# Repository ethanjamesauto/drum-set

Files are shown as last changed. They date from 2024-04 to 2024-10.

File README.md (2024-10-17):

## Project Overview
This project aims to produce an electronic drum set that is silent yet feels nearly identical to a real acoustic drum set. I've split the project into two phases:
* Phase 1 - creating a basic kit with a kick drum trigger and 2 drum pads as a proof-of-concept **(completed)**
* Phase 2 - creating a full drum kit with kick trigger, 4 drum pads, and 4 electronic cymbals **(in progress)**

## Full Outline

### Drum Module
* I'm currently using an ESP32 with [edrumulus](https://github.com/corrados/edrumulus/tree/main) and a custom-built analog frontend
  * The ESP32 has a drawback of not being a native MIDI device - it requires a script to appear as a virtual MIDI device
  * I'll be replacing it with a teensy 4.2, which solves this issue. Additionally, it has an SD card slot and plenty of processing power, so hopefully I'll be able to use it as a standalone synthesizer.
* I'm currently designing a PCB which includes the teensy, 8 input jacks, analog frontends for each channel, and display/keypad for controlling settings

Materials:
* Teensy 4.2
* 8x 1/4 inch PCB mount TRS audio jacks
* 16x2 character LCD
* Arduino numeric keypad
* 8x TRS audio cable

Features:
* Teensy 4.2 based - with headers for all GPIOs
* headers for piezo inputs (test points)
* i2c headers for display (VCC, GND, SDA, SCL)
* 8 gpios for numeric keypad

### Drum Pads
Materials:
  * Drum Shells
  * Drum top/bottom
  * M6x50mm bolts / M6 wing nuts (2x8 + 2x10 = 36 total)
  * Regular M6 nuts for attaching drum mount
  * M3x10mm bolts/nuts (already own)
  * 2x10in drum head, 2x12in drum head
  * piezos/trigger cones/audio jacks

Notes:
* All drum shells will be printed with [shell.scad](shell.scad) (my script for generating drum shells)
* Drum design is from [Open E-Drums](https://open-e-drums.com/hardware/download_pad_noshell.html)

### Hi-Hat
* Will likely use this [optical hi-hat controller](https://open-e-drums.com/hardware/download_hhc.html)

### Mounting Hardware
Rack will likely be a second-hand alesis e-drum rack

TODO:
* modify pcb to allow for optical hi hat sensor

Tom mounts:
*  [Alesis drum clamp mount](https://www.printables.com/model/244788-alesis-electronic-drum-clamp-mount) - these each require an Alesis L-rod
* Modify this [Roland mount](https://open-e-drums.com/hardware/download_mount.html) to change the hole from 11mm (Roland) to 9mm (Alesis)

Snare mount:
* ???

Cymbal Mounts:
* These could use the same alesis drum clamp mounts, but they require a cymbal mount instead of an L-rod (much more expensive)

Hi-Hat Mount:
* Real hi-hat stand. It's really not worth bothering with anything else.

## Members
Ethan James, Computer Engineering Student (2024) -
ethanjamesauto@vt.edu

## Images
Drum module PCB:
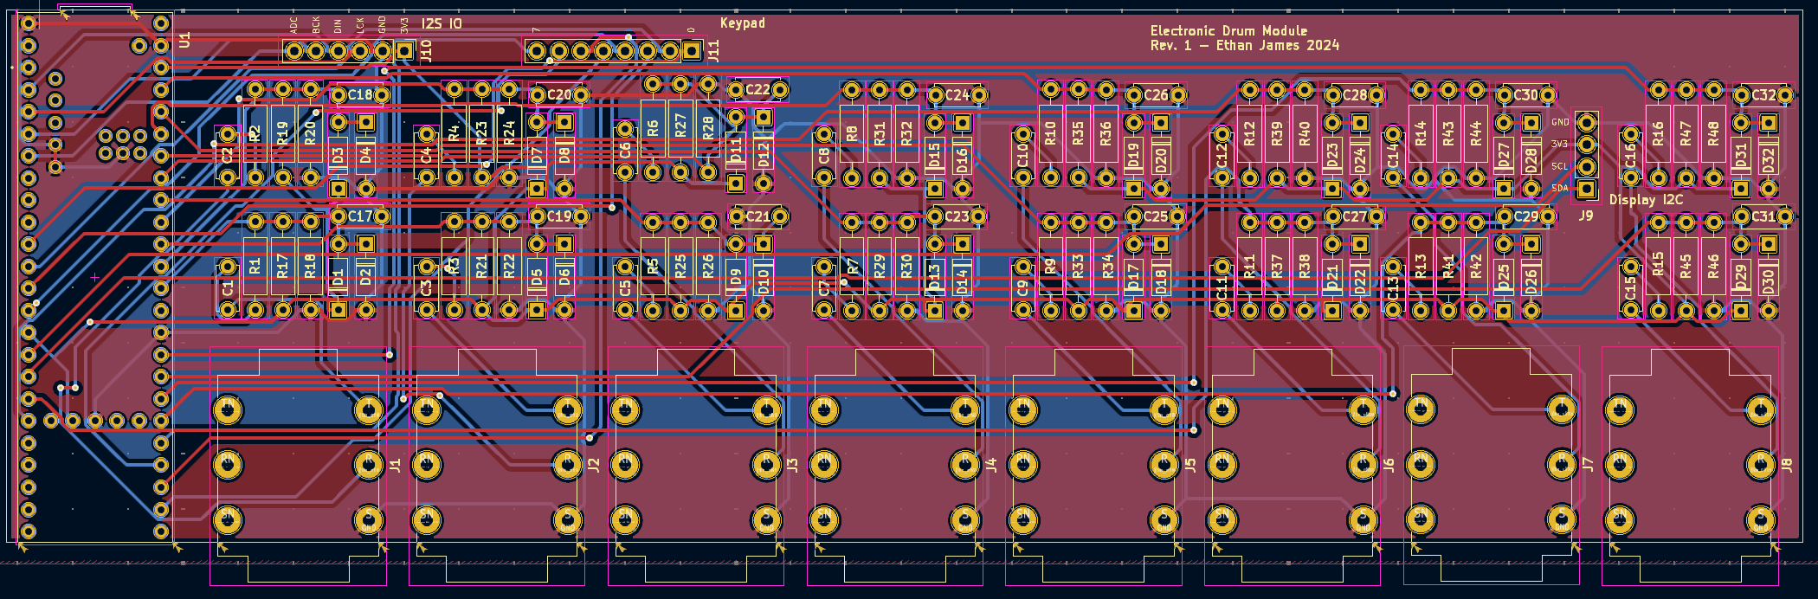
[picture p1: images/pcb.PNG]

This is the prototype (Phase 1):
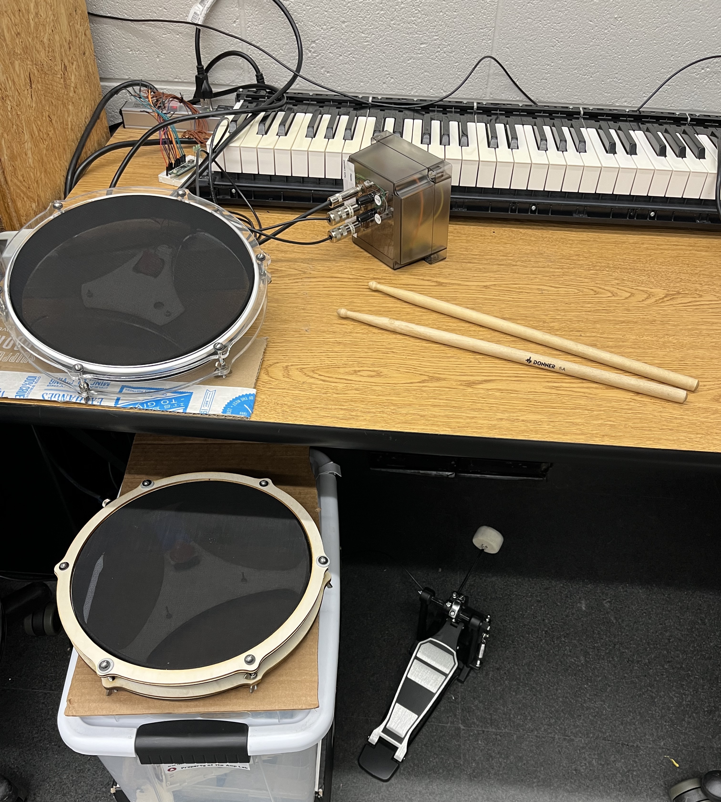
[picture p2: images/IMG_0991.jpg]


## Drum pad notes
* height from base plate is 47.5mm
* Trigger cones are 35mm tall
* Recommended height of trigger cone above shell is maybe 1.5mm or 1/16in
* definitely use spacers (3d printed or some other plastic) to adjust height of plate

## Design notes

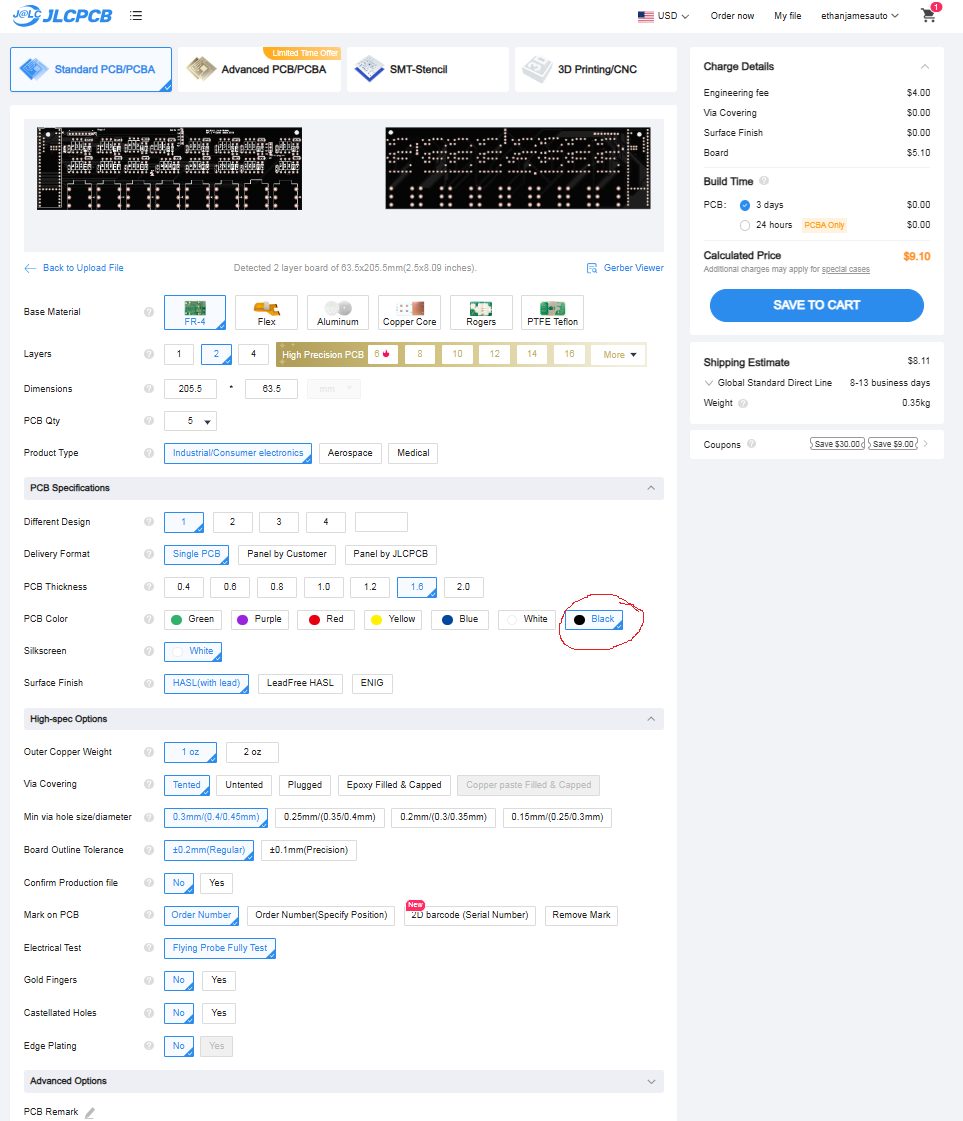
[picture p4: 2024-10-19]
drum_board/options.PNG

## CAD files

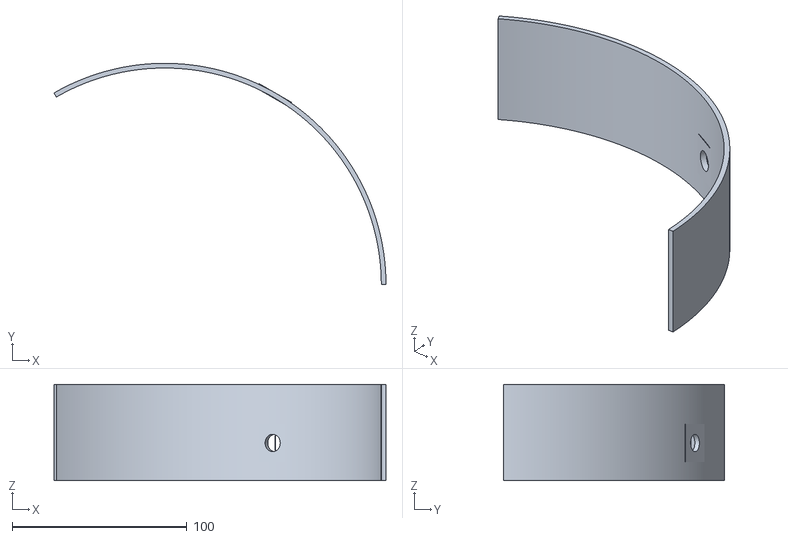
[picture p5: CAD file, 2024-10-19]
3d-print/shell_10in_jack.stl
190.2 x 126.8 x 55.0

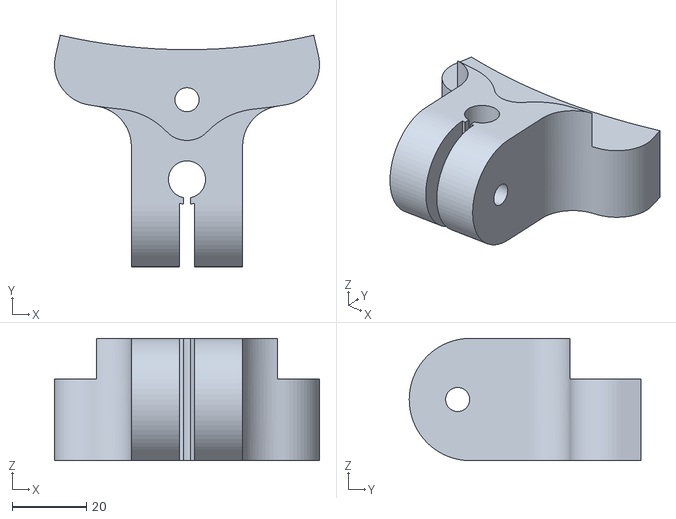
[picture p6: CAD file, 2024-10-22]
alesis-coupler/alesis.stl
71.5 x 62.5 x 33.0

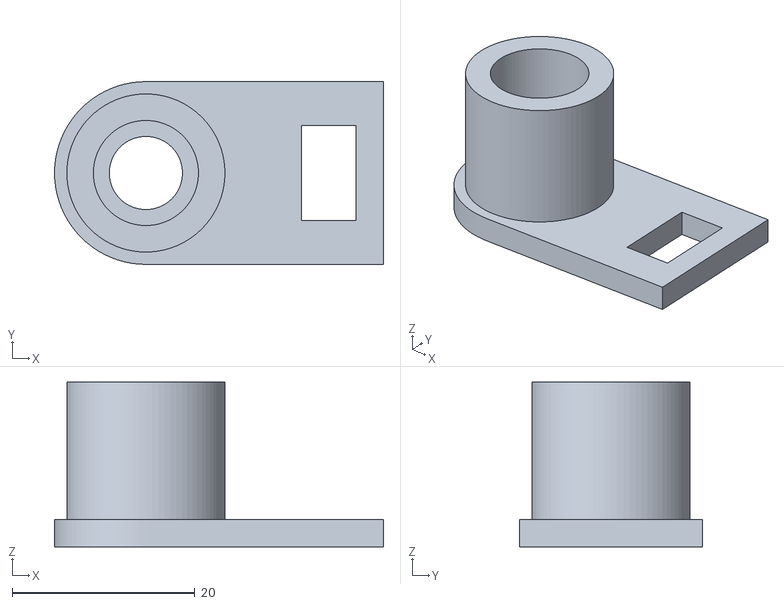
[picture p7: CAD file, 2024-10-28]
hi-hat-sensor/sensor.stl
36.0 x 20.0 x 18.0

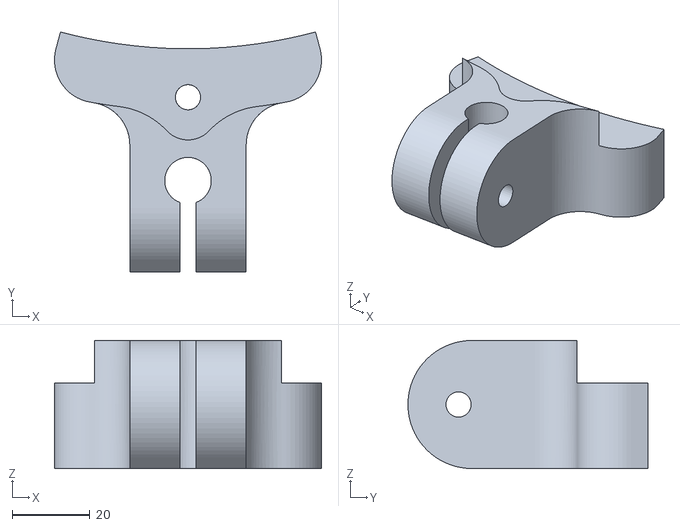
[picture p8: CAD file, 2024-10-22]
alesis-coupler/Mount_Roland_10_noshell.stl
68.8 x 61.9 x 33.0

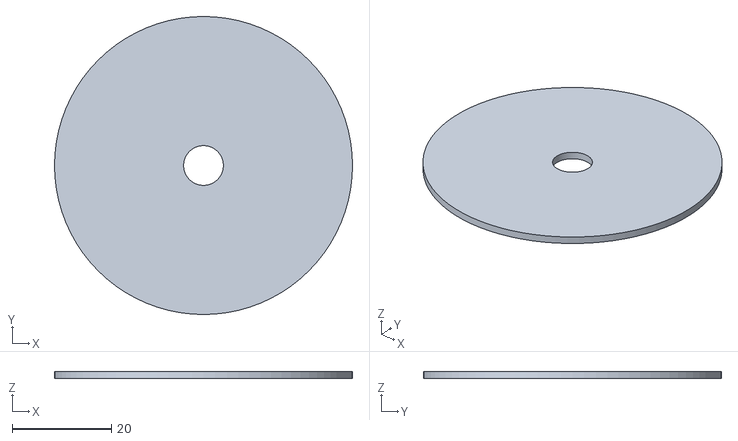
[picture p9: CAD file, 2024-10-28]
hi-hat-sensor/disc.stl
60.0 x 60.0 x 1.50

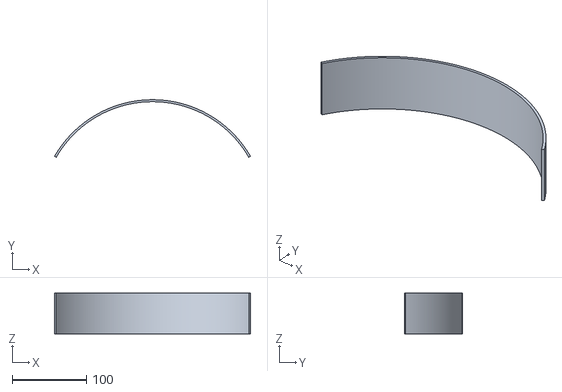
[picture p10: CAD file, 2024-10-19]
3d-print/shell_12in.stl
263.6 x 77.5 x 55.0

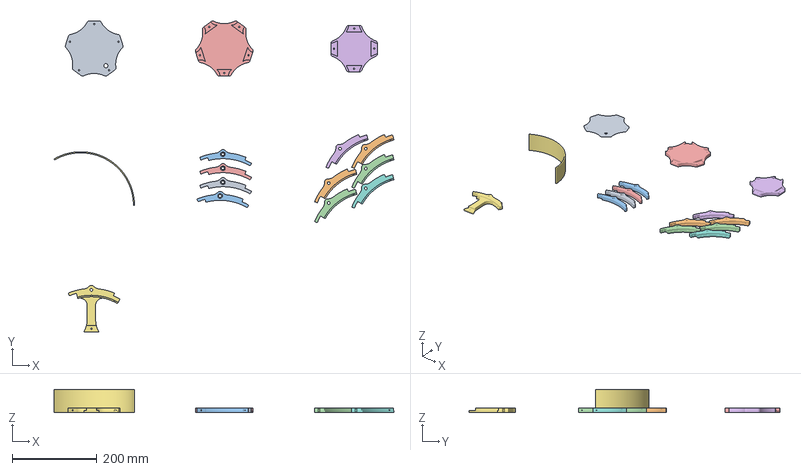
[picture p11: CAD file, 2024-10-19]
3d-print/drum_project.3mf
803.1 x 734.9 x 55.0 mm
sensorplate_12inch.stl
bottom2__noShell_10inch.stl x 6
rim_low_10inch.stl x 4
shell_10in.stl
bottom3_12inch.stl
bottom3_10inch.stl
bottom1_noShell_10inch.stl

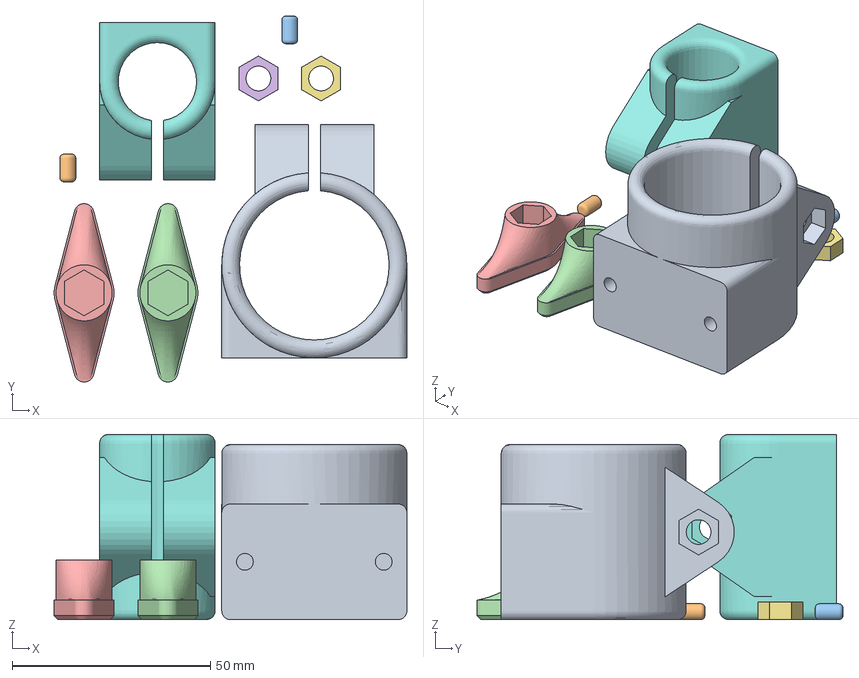
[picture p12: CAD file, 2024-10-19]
3d-print/Alesis Clamp II.3mf
89.0 x 92.3 x 46.7 mm
Alesis Clamp II-Big Clamp.stl
Alesis Clamp II-Dowel.stl
Alesis Clamp II-Knob.stl
Alesis Clamp II-Knob Insert.stl
Alesis Clamp II-Small Clamp.stl

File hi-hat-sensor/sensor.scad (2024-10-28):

// diameter of the hi-hat plastic thingy that the bottom hat rests on
stand_plastic_r = 11.3/2;

// radius of the hole the moving part fits through
hole_r = 8/2;

// outer diameter of this part
outer_r = 10;

// part thickness and height
thickness = 3;
height = 15;

tol_tight = 0.1;
tol_loose = 0.2;

platform_w = 26;
platform_h = outer_r*2;

tcrt_w = 10.2    + tol_tight*2;
tcrt_h = 5.8     + tol_tight*2;
tcrt_offset = 20 - tcrt_h/2;

disc_thick = 1.5;
disc_r = 30;

clutch_r = 9.3/2;

sensor_mount();
// disc();

module sensor_mount() {
	difference() {
		translate([0, 0, -thickness]) {
			cylinder(thickness, outer_r, outer_r, $fn=80);
			translate([0, -platform_h/2, 0]) cube([platform_w, platform_h, thickness]);
		}
		
		union() {
			translate([tcrt_offset, -tcrt_w/2, -thickness]) cube([tcrt_h, tcrt_w, thickness]);
			translate([0, 0, -thickness]) cylinder(thickness, hole_r, hole_r, $fn=80);
		}
	}

	difference() {
		cylinder(height, stand_plastic_r+thickness, stand_plastic_r+thickness, $fn=80);
		cylinder(height, stand_plastic_r+tol_tight, stand_plastic_r+tol_tight, $fn=80);
	}
}

module disc() {
	r = clutch_r + tol_loose;
	difference() {
		cylinder(disc_thick, disc_r, disc_r, $fn=80);
		cylinder(disc_thick, r, r, $fn=80);
	}
}

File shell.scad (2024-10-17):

module pieSlice(a, r, h){
  // a:angle, r:radius, h:height
  rotate_extrude(angle=a, $fn=500) square([r,h]);
}

// Note: no idea why there's a .008 here. It is equal to .2mm though - maybe it's a tolerance?
outer_rad = 10.008*25.4/2;	// 10 inch
// outer_rad = 12.008*25.4/2; 		// 12 inch

// thickness appears to be 3, so im doing 2.7
tol = 0.3;
tol_tight = 0.1;
tol_loose = 0.2;

// h = 32; // from the original drum prototype
h = 55;

rotate([0, 0, -30])
shell();

/*
rotate([0, 0, -30]) {
difference() {
	shell();
	jack(true, 1.8);
}
difference() {
	jack(true, 1.8);
	jack(false, 1.8);
}
}
//*/

module shell() {
	// from https://www.instructables.com/E-drum-With-Small-3D-Printer-and-Thick-Paper/
	rotate([0, 0, 30])
	difference() {
		pieSlice(120,outer_rad-tol,h);
		pieSlice(360, outer_rad-tol-2.7,h);
	}
}

module jack(cutout, offset) {
	// the top of the drum shell (that is not covered by the sides of the mesh head
	// is about 15mm from the top
	// the visible bottom is about 3mm from the bottom
	jack_height = ((h-15) + 3)/2;  // TODO: figure out
	jack_r = 9.6/2;
	hole_r = jack_r + tol_loose;
	cube_h = 3;
	cutout_h = jack_r*4.5;
	
	translate([0, outer_rad, jack_height])
	rotate([90, 0, 0]) {
		if (cutout)
			translate([0, 0, offset]) cube([cutout_h, cutout_h, cube_h], center=true);
		else
			cylinder(100, hole_r, hole_r, $fn=50);
	}
}

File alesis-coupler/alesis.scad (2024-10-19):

// The inner diameter of the 3d printed roland mount is 12mm
// the existing stl also uses an exactly 12mm hole
//*
translate([300, 0, 100]) 
import("Mount_Roland_12_noshell.stl");
//*/

inner = 9;
outer = 13.5;
h = 33;
fn = 50;
notch_w = 2;
notch_h = 20;

translate([-25, 11.5, 0])
translate([0, 0, -14.5])
difference () {
	cylinder(h, outer/2, outer/2, $fn=fn);
	union() {
		cylinder(h, inner/2, inner/2, $fn=fn);
		translate([-notch_w/2, -notch_h, 0])
			cube([notch_w, notch_h, h]);
	}

}

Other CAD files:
3d-print/shell_10in.stl
alesis-coupler/alesis_10.stl
alesis-coupler/Mount_Roland_12_noshell.stl
3d-print/shell_12in_jack.stl
alesis-coupler/alesis_10.scad

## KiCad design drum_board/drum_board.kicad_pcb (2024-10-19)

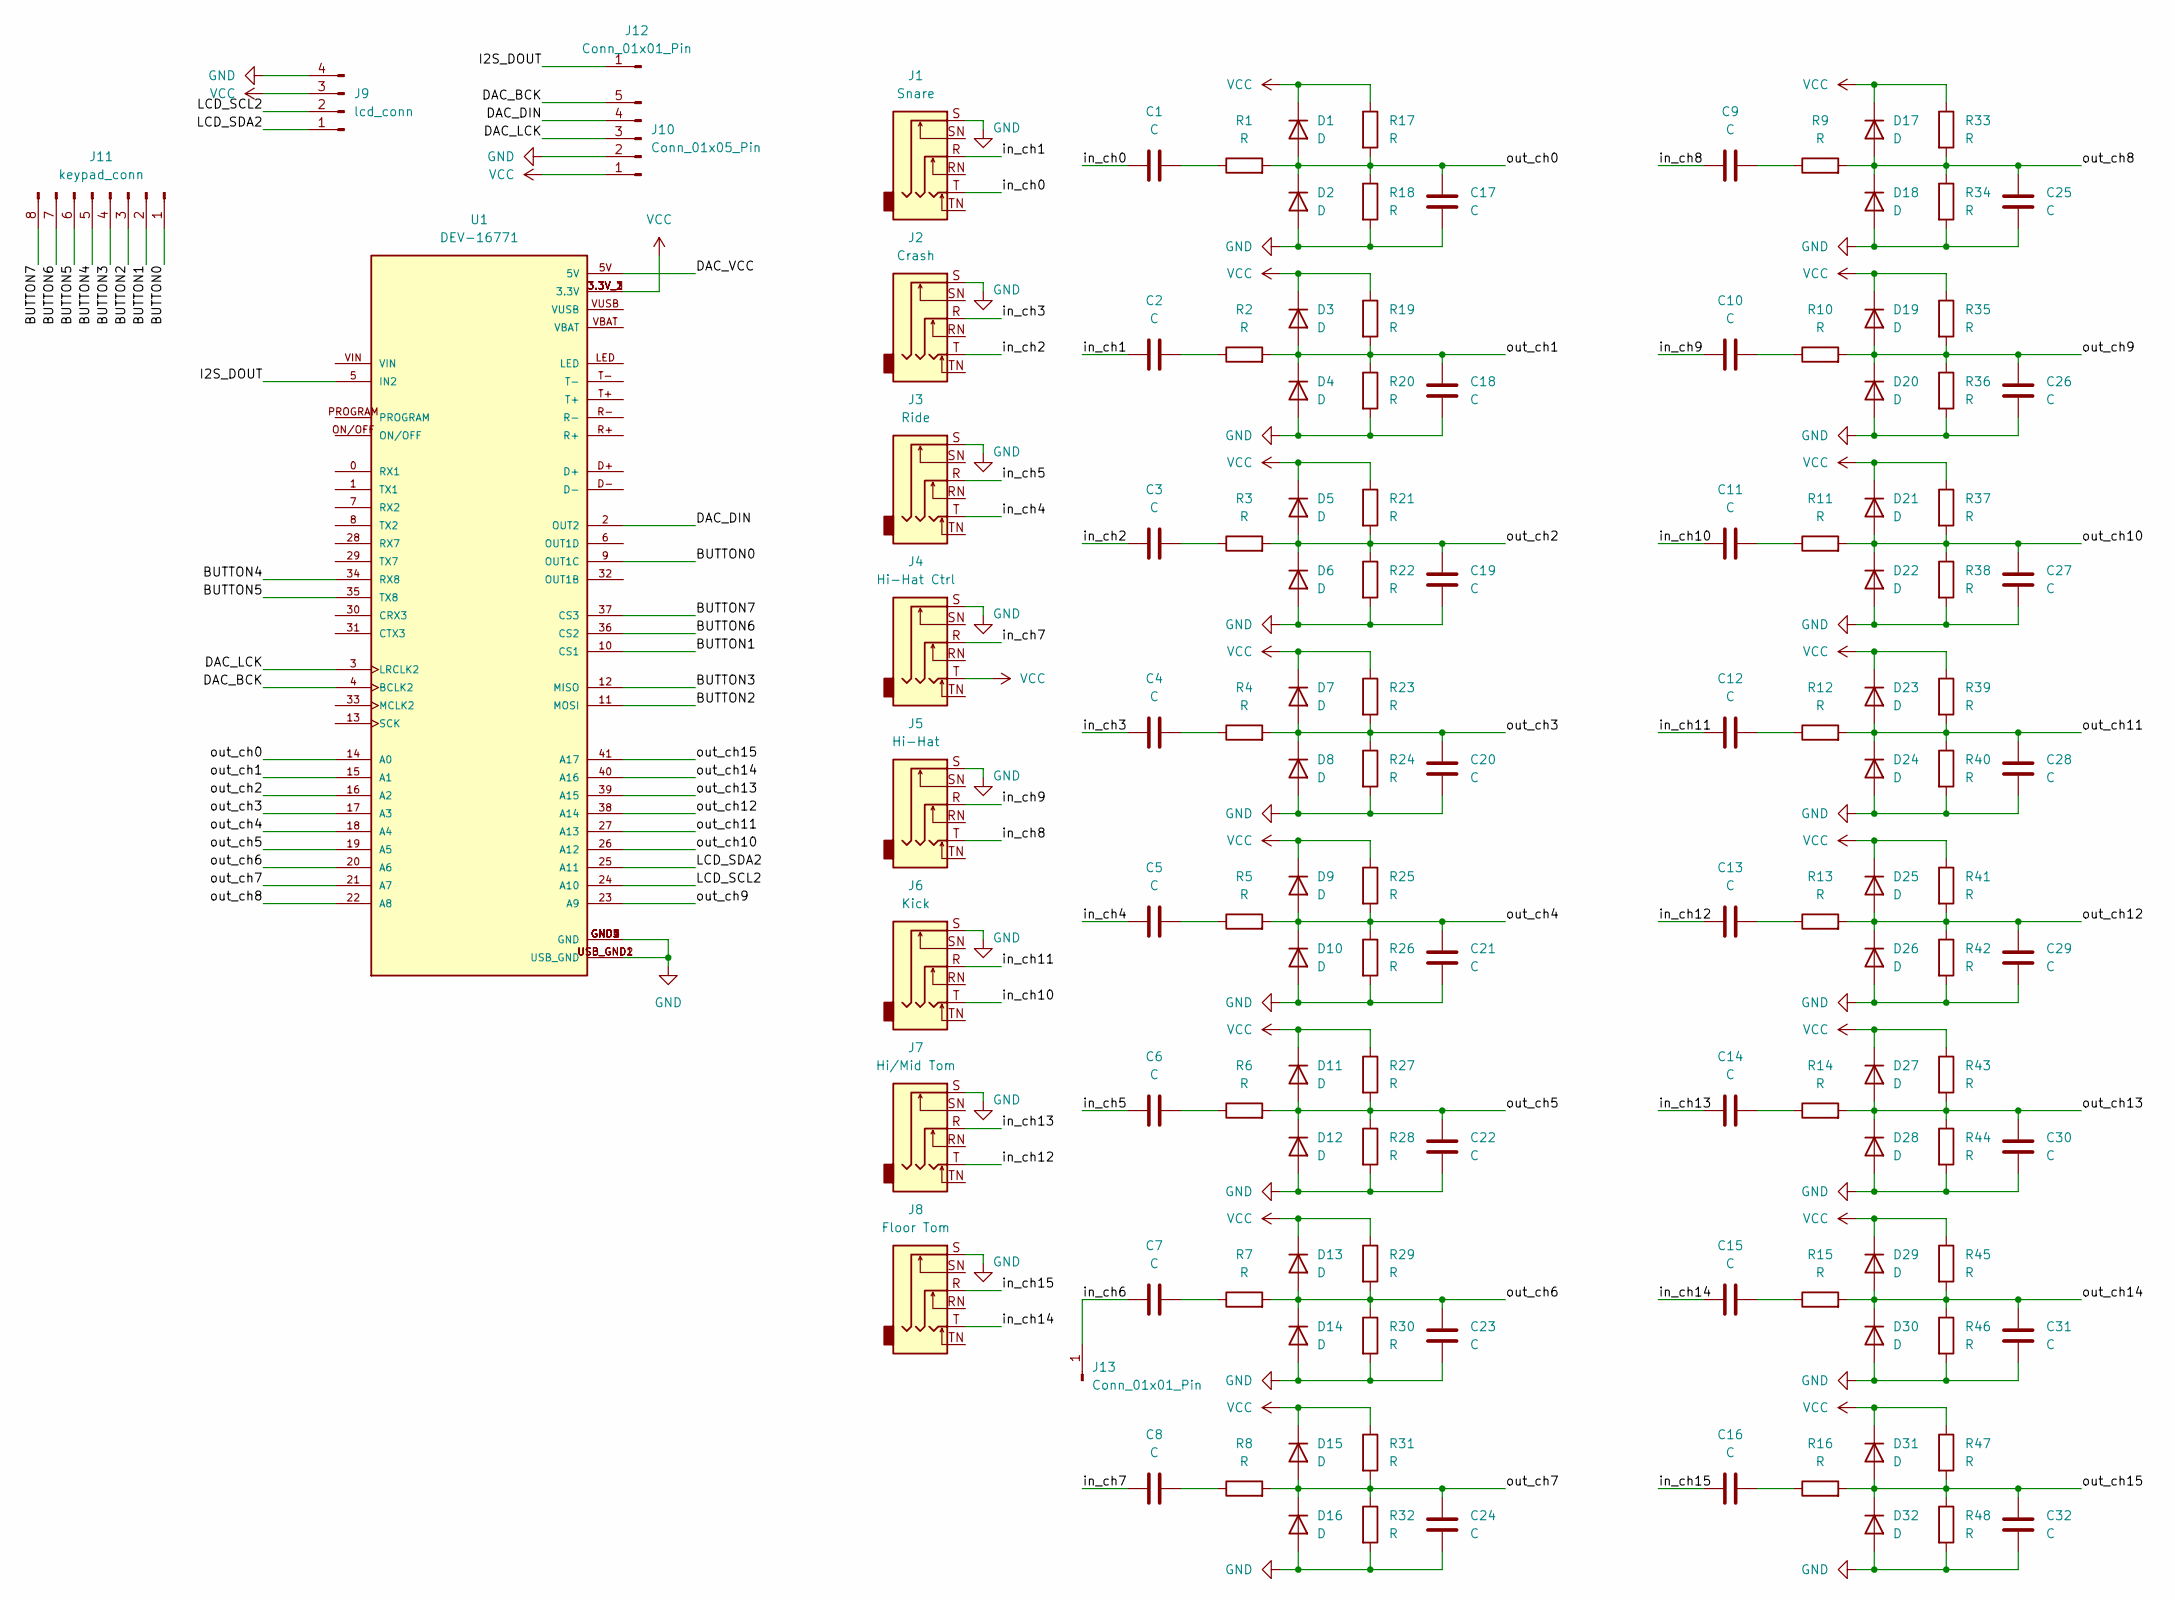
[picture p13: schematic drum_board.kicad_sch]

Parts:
C1, C2, C3, C4, C5, C6, C7, C8, C9, C10, C11, C12, C13, C14, C15, C16, C17, C18, C19, C20, C21, C22, C23, C24, C25, C26, C27, C28, C29, C30, C31, C32: C; C_Disc_D5.0mm_W2.5mm_P5.00mm
D1, D2, D3, D4, D5, D6, D7, D8, D9, D10, D11, D12, D13, D14, D15, D16, D17, D18, D19, D20, D21, D22, D23, D24, D25, D26, D27, D28, D29, D30, D31, D32: D; D_DO-35_SOD27_P7.62mm_Horizontal
J1: Snare; Jack_6.35mm_Neutrik_NMJ6HCD2_Horizontal
J2: Crash; Jack_6.35mm_Neutrik_NMJ6HCD2_Horizontal
J3: Ride; Jack_6.35mm_Neutrik_NMJ6HCD2_Horizontal
J4: Hi-Hat Ctrl; Jack_6.35mm_Neutrik_NMJ6HCD2_Horizontal
J5: Hi-Hat; Jack_6.35mm_Neutrik_NMJ6HCD2_Horizontal
J6: Kick; Jack_6.35mm_Neutrik_NMJ6HCD2_Horizontal
J7: Hi/Mid Tom; Jack_6.35mm_Neutrik_NMJ6HCD2_Horizontal
J8: Floor Tom; Jack_6.35mm_Neutrik_NMJ6HCD2_Horizontal
J9: lcd_conn; PinHeader_1x04_P2.54mm_Vertical
J10: Conn_01x05_Pin; PinHeader_1x05_P2.54mm_Vertical
J11: keypad_conn; PinHeader_1x08_P2.54mm_Vertical
J12, J13: Conn_01x01_Pin; PinHeader_1x01_P2.54mm_Vertical
R1, R2, R3, R4, R5, R6, R7, R8, R9, R10, R11, R12, R13, R14, R15, R16, R17, R18, R19, R20, R21, R22, R23, R24, R25, R26, R27, R28, R29, R30, R31, R32, R33, R34, R35, R36, R37, R38, R39, R40, R41, R42, R43, R44, R45, R46, R47, R48: R; R_Axial_DIN0207_L6.3mm_D2.5mm_P10.16mm_Horizontal
U1: DEV-16771; MODULE_DEV-16771; PARTREV 4.1

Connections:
/BUTTON0: J11.1, U1.9 (OUT1C)
/BUTTON1: J11.2, U1.10 (CS1)
/BUTTON2: J11.3, U1.11 (MOSI)
/BUTTON3: J11.4, U1.12 (MISO)
/BUTTON4: J11.5, U1.34 (RX8)
/BUTTON5: J11.6, U1.35 (TX8)
/BUTTON6: J11.7, U1.36 (CS2)
/BUTTON7: J11.8, U1.37 (CS3)
/DAC_BCK: J10.5, U1.4 (BCLK2)
/DAC_DIN: J10.4, U1.2 (OUT2)
/DAC_LCK: J10.3, U1.3 (LRCLK2)
/DAC_VCC: U1.5V
/I2S_DOUT: J12.1, U1.5 (IN2)
/LCD_SCL2: J9.2, U1.24 (A10)
/LCD_SDA2: J9.1, U1.25 (A11)
/in_ch0: C1.1, J1.T
/in_ch1: C2.1, J1.R
/in_ch2: C3.1, J2.T
/in_ch3: C4.1, J2.R
/in_ch4: C5.1, J3.T
/in_ch5: C6.1, J3.R
/in_ch6: C7.1, J13.1
/in_ch7: C8.1, J4.R
/in_ch8: C9.1, J5.T
/in_ch9: C10.1, J5.R
/in_ch10: C11.1, J6.T
/in_ch11: C12.1, J6.R
/in_ch12: C13.1, J7.T
/in_ch13: C14.1, J7.R
/in_ch14: C15.1, J8.T
/in_ch15: C16.1, J8.R
/out_ch0: C17.2, D1.2 (A), D2.1 (K), R1.2, R17.2, R18.1, U1.14 (A0)
/out_ch1: C18.2, D3.2 (A), D4.1 (K), R2.2, R19.2, R20.1, U1.15 (A1)
/out_ch2: C19.2, D5.2 (A), D6.1 (K), R3.2, R21.2, R22.1, U1.16 (A2)
/out_ch3: C20.2, D7.2 (A), D8.1 (K), R4.2, R23.2, R24.1, U1.17 (A3)
/out_ch4: C21.2, D9.2 (A), D10.1 (K), R5.2, R25.2, R26.1, U1.18 (A4)
/out_ch5: C22.2, D11.2 (A), D12.1 (K), R6.2, R27.2, R28.1, U1.19 (A5)
/out_ch6: C23.2, D13.2 (A), D14.1 (K), R7.2, R29.2, R30.1, U1.20 (A6)
/out_ch7: C24.2, D15.2 (A), D16.1 (K), R8.2, R31.2, R32.1, U1.21 (A7)
/out_ch8: C25.2, D17.2 (A), D18.1 (K), R9.2, R33.2, R34.1, U1.22 (A8)
/out_ch9: C26.2, D19.2 (A), D20.1 (K), R10.2, R35.2, R36.1, U1.23 (A9)
/out_ch10: C27.2, D21.2 (A), D22.1 (K), R11.2, R37.2, R38.1, U1.26 (A12)
/out_ch11: C28.2, D23.2 (A), D24.1 (K), R12.2, R39.2, R40.1, U1.27 (A13)
/out_ch12: C29.2, D25.2 (A), D26.1 (K), R13.2, R41.2, R42.1, U1.38 (A14)
/out_ch13: C30.2, D27.2 (A), D28.1 (K), R14.2, R43.2, R44.1, U1.39 (A15)
/out_ch14: C31.2, D29.2 (A), D30.1 (K), R15.2, R45.2, R46.1, U1.40 (A16)
/out_ch15: C32.2, D31.2 (A), D32.1 (K), R16.2, R47.2, R48.1, U1.41 (A17)
GND: C17.1, C18.1, C19.1, C20.1, C21.1, C22.1, C23.1, C24.1, C25.1, C26.1, C27.1, C28.1, C29.1, C30.1, C31.1, C32.1, D2.2 (A), D4.2 (A), D6.2 (A), D8.2 (A), D10.2 (A), D12.2 (A), D14.2 (A), D16.2 (A), D18.2 (A), D20.2 (A), D22.2 (A), D24.2 (A), D26.2 (A), D28.2 (A), D30.2 (A), D32.2 (A), J1.S, J2.S, J3.S, J4.S, J5.S, J6.S, J7.S, J8.S, J9.4, J10.2, R18.2, R20.2, R22.2, R24.2, R26.2, R28.2, R30.2, R32.2, R34.2, R36.2, R38.2, R40.2, R42.2, R44.2, R46.2, R48.2, U1.GND1 (GND), U1.GND2 (GND), U1.GND3 (GND), U1.GND4 (GND), U1.GND5 (GND), U1.USB_GND1 (USB_GND), U1.USB_GND2 (USB_GND)
unnamed: C1.2, R1.1
unnamed: C2.2, R2.1
unnamed: C3.2, R3.1
unnamed: C4.2, R4.1
unnamed: C5.2, R5.1
unnamed: C6.2, R6.1
unnamed: C7.2, R7.1
unnamed: C8.2, R8.1
unnamed: C9.2, R9.1
unnamed: C10.2, R10.1
unnamed: C11.2, R11.1
unnamed: C12.2, R12.1
unnamed: C13.2, R13.1
unnamed: C14.2, R14.1
unnamed: C15.2, R15.1
unnamed: C16.2, R16.1
VCC: D1.1 (K), D3.1 (K), D5.1 (K), D7.1 (K), D9.1 (K), D11.1 (K), D13.1 (K), D15.1 (K), D17.1 (K), D19.1 (K), D21.1 (K), D23.1 (K), D25.1 (K), D27.1 (K), D29.1 (K), D31.1 (K), J4.T, J9.3, J10.1, R17.1, R19.1, R21.1, R23.1, R25.1, R27.1, R29.1, R31.1, R33.1, R35.1, R37.1, R39.1, R41.1, R43.1, R45.1, R47.1, U1.3.3V_1 (3.3V), U1.3.3V_2 (3.3V), U1.3.3V_3 (3.3V)

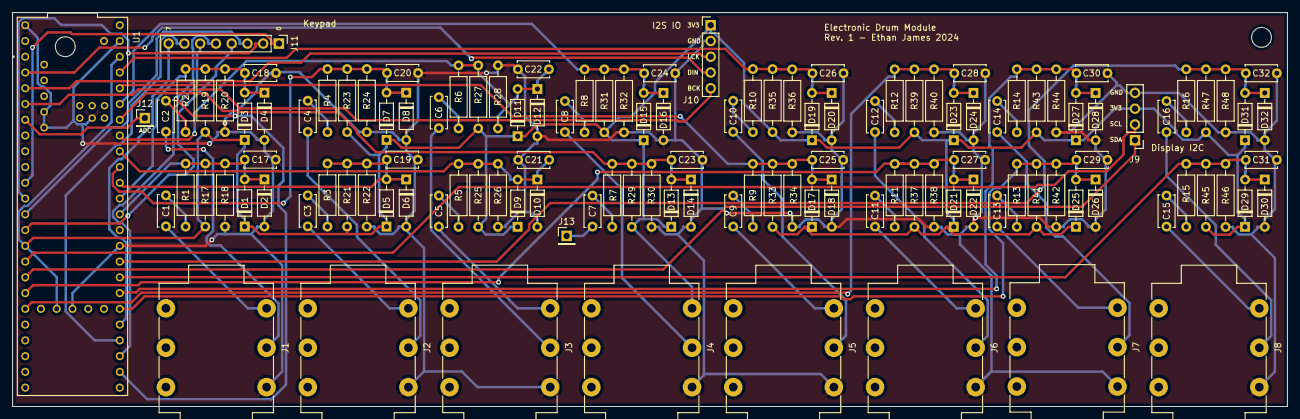
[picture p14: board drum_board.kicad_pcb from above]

Board: 2 copper layers, 205.5 x 63.5 mm, 126 parts (0 on the bottom side), 64 nets.

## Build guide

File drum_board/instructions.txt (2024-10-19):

JLCPCB Ordering Instructions
1. Please visit www.jlcpcb.com and select "Add gerber file"
2. Select "gerbers.zip" in the file explorer popup, then press "Instant Quote".
3. Leave all ordering options as their default values, except "PCB Color". For reference, the ordering options are contained in "options.png". Options that must be changed are circled in red.
4. Please choose a shipping option other than "Global Standard Direct Line" unless unable to do otherwise.

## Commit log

2024-09-13 Add project files and update README
    [shell.scad]
2024-10-17 Add new alesis drum coupler
    [Mount_Roland_12_noshell.stl, alesis.scad]
2024-10-17 Update shell design
    [shell.scad]
2024-10-20 Add untracked files
    [alesis-mount.stl]
2024-10-22 Fix bad alesis mount dimensions
    [Mount_Roland_10_noshell.stl, alesis-mount.stl, alesis.stl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]
2024-10-28 Add hi hat sensor model
    [disc.stl, sensor.scad, sensor.stl]
